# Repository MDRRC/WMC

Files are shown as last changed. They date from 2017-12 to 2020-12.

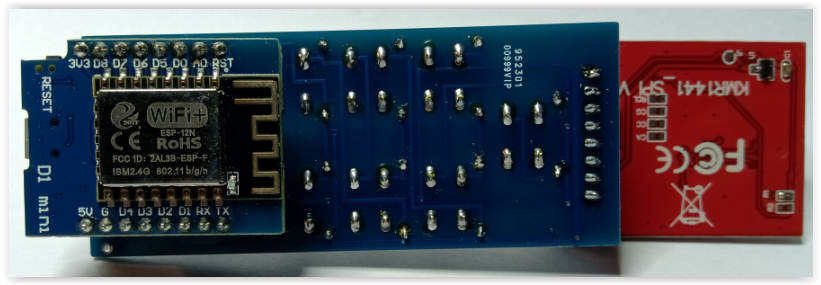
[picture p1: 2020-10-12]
Images/wmc_back.PNG

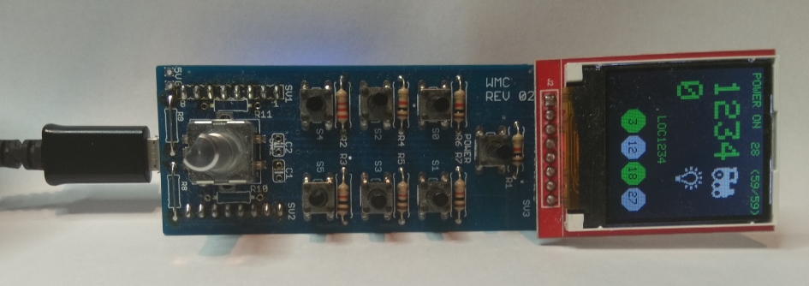
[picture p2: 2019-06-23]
Images/wmc_locname.jpg

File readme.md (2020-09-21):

Wifi Manual Control
=====================

The Wifi Manual Control (Wmc) is a project which supports the [Z21 protocol](https://www.z21.eu/en) of [Roco](https://www.roco.cc/en/home/index.html) to control locomotives and turnouts. Also CV's can be read and written. 
The design is based on an ESP8266-12E processor (Wemos Mini D1 for example), an ST7735 1.44 inch display, rotary (pulse) switch and some push buttons. 
For more info see the [wiki](https://github.com/MDRRC/WMC/wiki).

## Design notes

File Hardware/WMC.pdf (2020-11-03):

WMC

# WMC

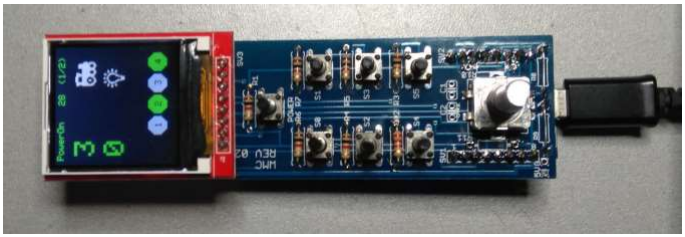
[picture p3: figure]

Version 4 | 3/11/2020 | 1 van 8

## Inhoudsopgave

Version 4 | 3/11/2020 | 2 van 8

1. Introduction.

This document describes how to mount components on the WMC PCB (REV 02) and how to pogram the ESP8266 module withput the need for installing Arduino¹
on a
system and building all code.

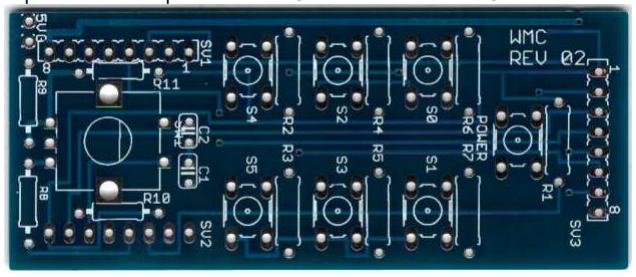
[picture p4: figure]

A description of how to operate the WMC can be found on the Github wiki²

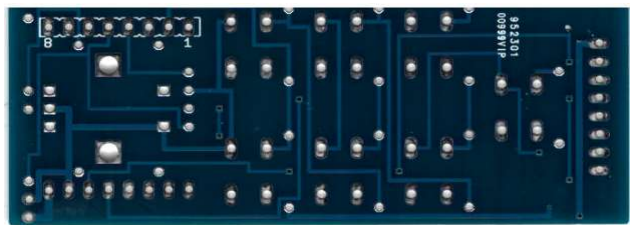
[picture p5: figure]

### 1.1 Used components

- Wemos ESP8266 D1 mini³
- S7735 display. Buy the so called “Replace Nokia 5110/3310 LCD”. Other displays will work but might not be directly soldered on connector SV3 as they might be not pin compatible.
- Some resistors, see schematic for values.
- 7 push buttons DIP P4
- Pulse switch (rotary pulse swith)

### 1 https://www.arduino.cc/ 2 https://github.com/MDRRC/WMC/wiki 3 https://wiki.wemos.cc/products:d1:d1_mini

Version 4 | 3/11/2020 | 3 van 8

2. Soldering components.
1. Solder the push buttons and the resistors.

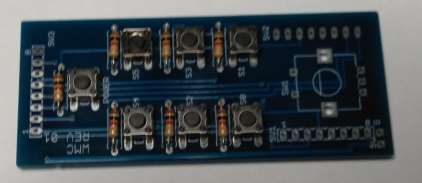
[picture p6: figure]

### 2. Solder the pulse switch and cut the solder points very short (solder points

marked with yellow arrow) so they can not make contact with the Wemos ESP8266 module.

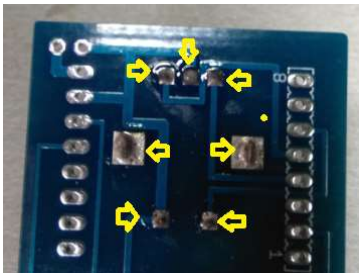
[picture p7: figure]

Version 4 | 3/11/2020 | 4 van 8

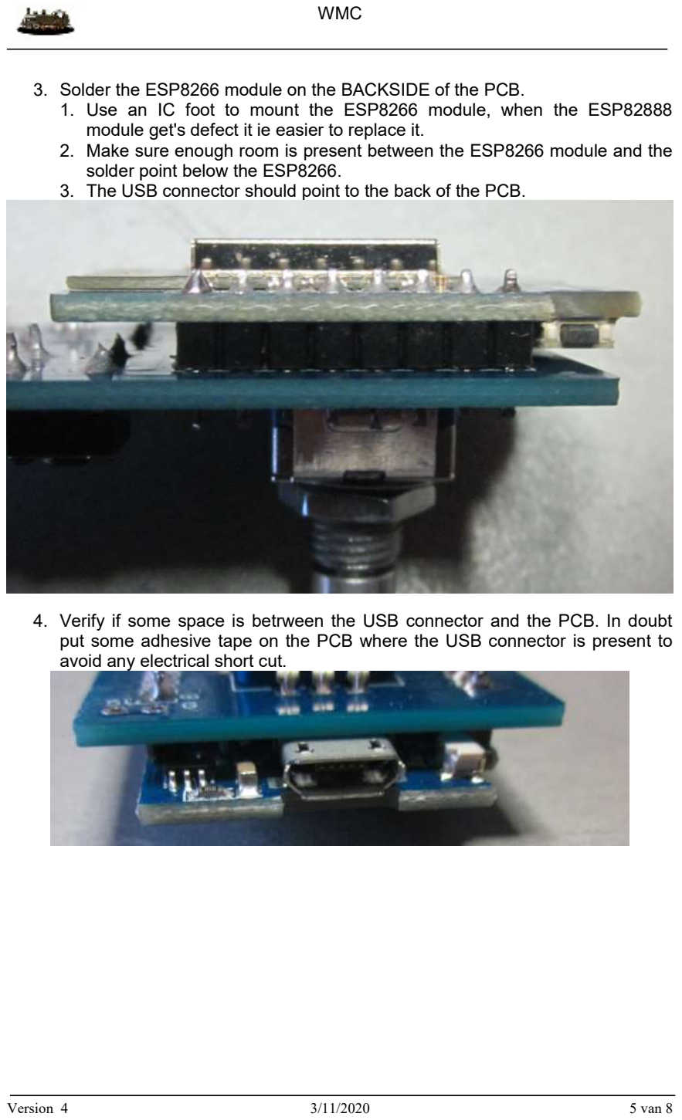
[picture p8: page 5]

3. Solder the ESP8266 module on the BACKSIDE of the PCB.

### 1. Use an IC foot to mount the ESP8266 module, when the ESP82888

module get's defect it ie easier to replace it.

### 2. Make sure enough room is present between the ESP8266 module and the

solder point below the ESP8266.
3. The USB connector should point to the back of the PCB.

### 4. Verify if some space is betrween the USB connector and the PCB. In doubt

put some adhesive tape on the PCB where the USB connector is present to avoid any electrical short cut.

Version 4 | 3/11/2020 | 5 van 8

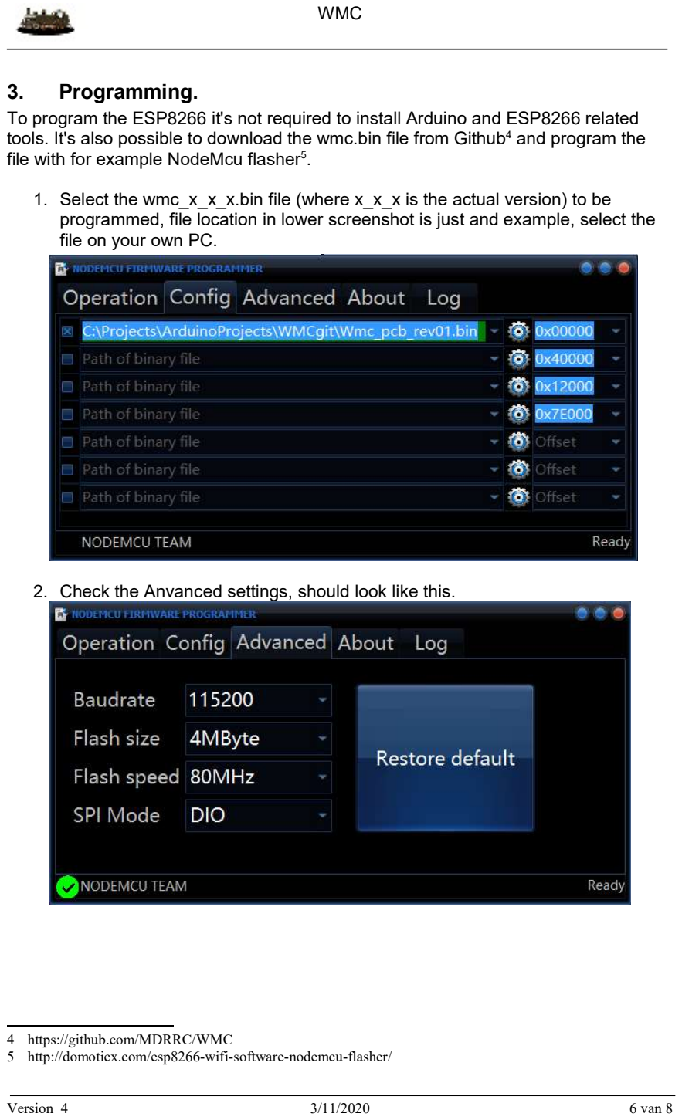
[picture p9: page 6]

3. Programming.
To program the ESP8266 it's not required to install Arduino and ESP8266 related tools. It's also possible to download the wmc.bin file from Github⁴
and program the
file with for example NodeMcu flasher⁵

### 1. Select the wmc_x_x_x.bin file (where x_x_x is the actual version) to be

programmed, file location in lower screenshot is just and example, select the file on your own PC.

2. Check the Anvanced settings, should look like this.

### 4 https://github.com/MDRRC/WMC 5 http://domoticx.com/esp8266-wifi-software-nodemcu-flasher/

Version 4 | 3/11/2020 | 6 van 8

### 3. Select the com port of the ESP8266 module and press Flash. Takes some

time to program...

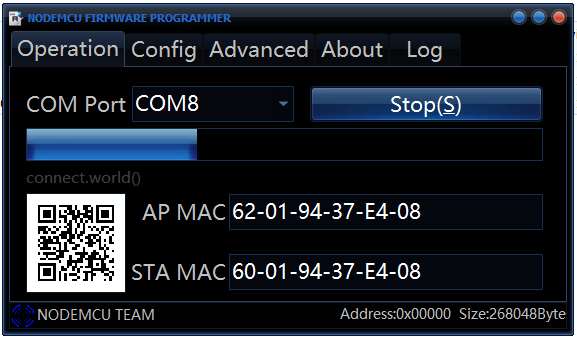
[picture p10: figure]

Version 4 | 3/11/2020 | 7 van 8

4. Changes.
Version | Date | Desciption
1 | 05-05-18 | Initial version
2 | 17-05-18 | 1 Introduction. Added link to how to operate the WMC. 3 Programming. Filename and screenshot updated.
3 | 17-11-18 | Some PCB images updated. 3 Programming. Filename updated.
4 | 03-11-20 | 1.1 Used components Test of resistors updated.
Version 4 | 3/11/2020 | 8 van 8

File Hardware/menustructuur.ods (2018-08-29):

Hoe te gebruiken | betreft | PushButton PB | D0 1 / 0 Power button | S0 | S1 | S2 | S3 | S4 | S5 | Puls schakelaar
rijden |  |  | aan uit 1 / 0
 |  | <200ms loc stop OF richting als snelheid al 0 is |  | licht / functie | functie | functie | functie | functie | wisselmodus | snelheid
 |  | 1 sec richting
 |  | >3 sec POM
wisselmodus |  |  |  |  |  |  |  |  | activeren
 |  | <200ms = 1 |  | adres +1 | Adres +10 | Adres +100 | Adres +1000 | wissel L | wissel R | adres
 |  | 1 sec = locbesturing
MENU_1 |  |  | PowerOff |  |  |  |  |  |  | Menu 2
 |  | >4 sec
ADD (S1) |  |  |  |  | ADD loc toevoegen
loc toevoegen | loc | OK |  | Loc + 1 | Loc + 10 | Loc + 100 | Loc + 1000 | Adres = 1 | OK | loc selecteren
functies toekennen | functie | OK |  | licht F0 OF ken andere fucntie toe | ken functie toe aan knop (maar geen F0) | ken functie toe aan knop (maar geen F0) | ken functie toe aan knop (maar geen F0) | ken functie toe aan knop (maar geen F0) | OK | kies functie nr.
 |  |  | afsluiten
CHANGE (S2) |  |  | PowerOff |  |  | CHANGE functie wijzigen
functie wijzigen | Selecteer loc | gedrukt houden |  |  |  |  |  |  |  | loc selecteren
 | functie | OK |  | licht F0 OF ken andere fucntie toe | ken functie toe aan knop (maar geen F0) | ken functie toe aan knop (maar geen F0) | ken functie toe aan knop (maar geen F0) | ken functie toe aan knop (maar geen F0) | OK | kies gewenste functie
 |  |  | ga terug naar het MENU
DELETE (S3) |  |  | PowerOff |  |  |  | DELETE verwijder loc
Verwijder een loc | Selecteer loc | OK |  |  |  |  |  |  |  | selecteer loc
 |  | >1 sec verwijder loc |  | ga terug naar het MENU | ga terug naar het MENU | ga terug naar het MENU | ga terug naar het MENU | ga terug naar het MENU | ga terug naar het MENU
 |  |  | ga terug naar het MENU
MENU_2 |  |  | PowerOff |  |  |  |  |  |  | Menu 1
 |  | >4 sec
DELL LOCS (S1) | Verwijder ALLE locomotieven
DELL ALL (S2) | Verwijder ALLE data
CV PROG (S4) |  |  | PowerOff |  |  |  |  | CV PROG cv programmeren op programmeer rail
 | loc op programmeerrail
 |  | <200msec = terug naar MENU > 1sec Naar Cv nummer Naar CV waarde Schrijf waarde |  | waarde +1 | Waarde +10 | Waarde +100 | Waarde +1000 | Cv nummer = 1 CV waarde = 1 | Lees waarde Schrijf waarde | selecteer waarde CV nummer
 |  |  | ga terug naar het MENU
POM PROG (S5) |  |  | schakel AAN 1 / 0 PowerOn |  |  |  |  |  | POM PROG CV programmeren POM
 | loc |  |  |  |  |  |  |  |  | loc selecteren
 |  | <200msec = terug naar menu > 1sec Naar Cv nummer Naar CV waarde Schrijf waarde |  | waarde +1 | Waarde +10 | Waarde +100 | Waarde +1000 | Pom adres = 1 Cv nummer = 1 Cv waarde = 1 | Naar Cv nummer Naar CV waarde Schrijf waarde | selecteer waarde CV nummer
 |  |  | ga terug naar het MENU

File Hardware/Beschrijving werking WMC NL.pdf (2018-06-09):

30-5-2018

## WMC

Dit is een vertaling van de originele beschrijving van Robert Evers. Deze vertaling is gemaakt voor eigengebruik. Eventuele fouten hierin komen dus volledig door mijn¹
vertaalkunsten en gebruiken is dan ook geheel voor eigen risico. Ieder die een actuele beschrijving wenst te hebben moet deze bij Robert Evers betrekken bijvoorbeeld via https://github.com/MDRRC/WMC/wiki
Met enkele goedkope componenten kan een eenvoudige op Wifi gebaseerde handmatige bediening worden gemaakt voor het Z21 protocol. (http://www.z21.eu/en) Het is volgende is mogelijk:
- Rijsnelheid, richting en functies van locomotieven.
- Wissels instellen (accessoire-decoders).
- Programmeren CV's van locdecoders (Programmeerrail en POM)

De NodeMcu kan worden geprogrammeerd met de Arduino-omgeving, u moet ondersteuning voor de ESP8266 installeren in de Arduino-omgeving. (gebruik op eigen risico !!!!). Het display is een 128 * 128 pixel ST7735 LCD-scherm.
De WMC is (nog) niet getest met een Roco (http://www.roco.cc/en/home/index.html) (z) / Z21 Wifi-commandostation, alleen met
- MDRRC-II (http://members.home.nl/robert.evers/mdrrc2.htm)
- DigiKeys DR 5000 (CV / POM (https://www.digikeijs.nl/dr5000adj-dcc-multi-bus-centrale.html) niet getest (https://www.digikeijs.nl/dr5000adj-dcc-multi-bus-centrale.html) ) (https://www.digikeijs.nl/dr5000adj-dcc-multi-bus-centrale.html)
- DIY Z21 Emulator (CV / POM (https://www.gscalecentral.net/threads/diy-emulator-of-z21-command-station-based-on-arduino-for-20.305794/) niet getest (https://www.gscalecentral.net/threads/diy-emulator-of-z21-command-station-based-on-arduino-for-20.305794/) ). (https://www.gscalecentral.net/threads/diy-emulator-of-z21-command-station-based-on-arduino-for-20.305794/)

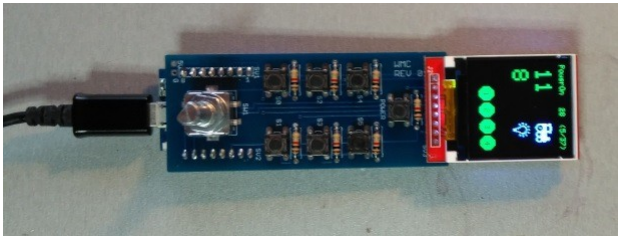
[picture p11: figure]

Hoe te gebruiken.

Programmeer eerst de SSID (Wifi) -naam, het wifi-wachtwoord en het Z21-control-IP-adres met behulp van de commandoregel-interface, zie verder onder.

1 http://members.home.nl/pamali/

De drukknop op D0 is de Aan / Uitknop.

- Als de stroom is ingeschakeld, draait u de pulsschakelaar links / rechts om de snelheid van de geselecteerde locomotief te regelen.
- Kort indrukken (~ 200msec) en het loslaten van de pulsschakelaar is de locomotief-stop.
- Normale druk (~ 1sec) en het loslaten van de pulsschakelaar is de richting van de locomotief omdraaien.
- Lang indrukken (> 3 sec.) En loslaten van pulsschakelaar is POM-programmeermodus voor locomotieven.
- Druk op een van de functieknoppen om de geprogrammeerde functie om te schakelen wanneer de knop wordt losgelaten.
- Door op S5 te drukken en los te laten, wordt de wisselmodus ingevoerd.
- Om een andere loc te selecteren, drukt en draait u de pulsschakelaar om een geprogrammeerde loc te selecteren.
- Als een geselecteerde loc al in gebruik is door een ander apparaat, wordt het loc-symbool op het scherm geel.

Wissel modus

- Druk op de knoppen SO ... S3 om het adres te verhogen door de pulsschakelaar te draaien.
- Druk op S4 of S5 om de richting van de wissel te veranderen.
- Druk kort op de pulsdrukknop om het wisseladres opnieuw in te stellen op 1.
- Normale druk op pulsschakelaar is terug naar locomotiefbesturing.

MENU

- Zorg ervoor dat PowerOff is weergegeven.
- Druk gedurende ten minste 4 seconden op de drukknop van de pulsschakelaar.
- Een menu verschijnt.

Locomotieven toevoegen (ADD)

- Druk op knop S1 om locomotieven toe te voegen
- Draai de pulsschakelaar om het loc-adres te selecteren. Met de knoppen S1 – S4 kunnen adressen worden verhoogd met 1,10,100 en 1000. Met knop 0 kan het adres worden gereset naar 1.
- Als het gewenste adres in orde is, drukt u op de pulsschakelaarknop.
- Als het adres een rode kleur wordt, is het adres al aanwezig in WMC.
- Ken nu functies toe aan de knoppen. Draai de pulsschakelaar, en kies een functie, wanneer de functie bereikt is, druk op de bijbehorende functieknop. Knop 0 kan alleen licht schakelen.
- Om de toegevoegde loc op te slaan, drukt u op de drukknop van de pulsschakelaar.
- Om het toevoegen van locomotieven af te sluiten, drukt u op de aan / uitknop D0.

Functies wijzigen (CHANGE)

- Kies in het menu knop S2 CHANGE – Wijzigen.
- Druk en draai de pulsschakelaar om de locomotief te selecteren.
- Draai de pulsschakelaar naar de gewenste functie.
- Druk op de toepasselijke functieknop.
- Druk op de schakelaar van de pulsschakelaar om de gegevens op te slaan.
- Het loc-adres zal geel worden, om te bevestigen dat de wijziging is opgeslagen.
- Om Wijzigen van de loc-functies te verlaten, drukt u op de Aan / Uit - knop D0.

Verwijder een loc. (DELETE)

- Selecteer in het menu knop S3 DELETE – Verwijderen.
- Draai aan de pulsschakelaar om de locomotief te selecteren die moet worden verwijderd.
- Druk op de pulsschakelaarknop om de loc te verwijderen.
- Druk op de aan / uitknop D0 om het verwijderen van locs af te sluiten.

Programmeren CV's op programmeerrail (CV PROG)

- Selecteer in het menu knop S4 CV Prog.
- Draai de pulsschakelaar om het CV-nummer te wijzigen en / of druk op de knoppen 1 .. 3 om de waarde te verhogen.
- Druk op knop S0 om het CV-nummer te resetten.
- Druk na het invoeren van het CV-nummer op> 1sec op de pulsschakelaar-drukknop (en laat los), de waarde zal worden gelezen.
- Nadat de CV-waarde is afgelezen, draait u de pulsschakelaar om het CV-nummer te wijzigen en / of drukt u op de knoppen 1 .. 3 om de waarde te verhogen.
- Druk op knop S0 om de CV-waarde te resetten.
- Druk na het invoeren van de CV-waarde op> 1 sec. Op de pulsdrukknop (en laat los), de waarde wordt geschreven.
- Druk nogmaals > 1sec op de pulsschakelaar- drukknop, om de waarde te lezen.
- Druk Aan / Uit - knop D0 om terug te keren naar het MENU (een stap terug)
- Druk Aan / Uit - knop D0 om terug te keren naar het LOC – MENU (een stap terug)
- Als u tijdens het invoeren van het CV-nummer of de CV-waarde op de Aan / Uit -knop D0 drukt, keert u terug naar het hoofdmenu.

Programmeren CV's met POM (POM PROG)

- Druk Aan / Uit - knop D0
- Power is ON
- Selecteer in het menu knop S5 POM PROG
- Procedure is hetzelfde als hierboven, maar eerst moet de gewenste locomotief worden ingevoerd.
- De cv-waarde wordt NIET gelezen.

Commandoregel-interface met Putty of Realterm.

Met Putty (http://www.putty.org/) of Realterm (https://sourceforge.net/projects/realterm/) opent u bijvoorbeeld de seriële poort van de NodeMcu, baudrate 115200.
Met de (eenvoudige) opdrachtregelinterface kunt u dit doen:
help | Het complete menu met alle opdrachtregels
add | Voeg een loc toe.
del | Verwijder een loc.
change x y z | Toegewezen functies wijzigen in knoppen van een locomotief. (adres=x, ftoets=y, functie=z)
ssid < > | Stel SSID (Wifi) naam in. (<wifi naam>)
Password < > | Stel wifi-wachtwoord in. (<paswoord>)
z21 a.b.c.d | Stel het IP-adres in waarmee het Z21-besturingselement verbinding maakt.
static x | Schakel tussen statisch en dynamisch IP-adres van de WMC (x=0). In de statische modus (x=1) moet u het IP-adres van de WMC invoeren.

Aansluitingen

NodeMcu | onderdeel
D0 | Drukknop naar massa en 1K weerstand naar 3V3 voedingsspanning voor
| pullup (geen draai/drukknop met voorgemonteerde weerstanden gebruiken!)
D1 | DC ST7735-display
D2 | RES ST7735-display
D3 | SCL ST7735-display
D4 | SDA ST7735-display
D5 | CLK draaischakelaar
D6 | DATA draaischakelaar
D7 | Drukknop draaischakelaar (geen draai/drukknop met voorgemonteerde
| weerstanden gebruiken!)
D8 | CS ST7735-display
A0 | Analoge ingang voor functieschakelaars, zie hieronder.

Schema zie h (https://github.com/MDRRC/WMC/blob/master/Hardware/wmc_schematic.pdf) ier (https://github.com/MDRRC/WMC/blob/master/Hardware/wmc_schematic.pdf). (https://github.com/MDRRC/WMC/blob/master/Hardware/wmc_schematic.pdf)

Gebruikte bibliotheken

- WmcStm (https://github.com/MDRRC/WmcStm) the state machine of the application.
- TinyFsm (https://github.com/digint/tinyfsm) for state machine framework.
- Z21 Slave (https://github.com/MDRRC/Z21Slave) for Z21 protocol.
- Bounce2 (https://github.com/thomasfredericks/Bounce2) for debouncing a switch.
- Adafruit-ST7735-Library (https://github.com/adafruit/Adafruit-ST7735-Library) to control the display.
- WmcTft (https://github.com/MDRRC/WmcTft) for graphics within the Wmc application.
- Adafruit-GFX-Library (https://github.com/adafruit/Adafruit-GFX-Library) for graphic control of the display.

- LocLib (https://github.com/MDRRC/LocLib) for handling locomotive data within the Wmc application. WmcCv (https://github.com/MDRRC/WmcCv) for changing CV's.

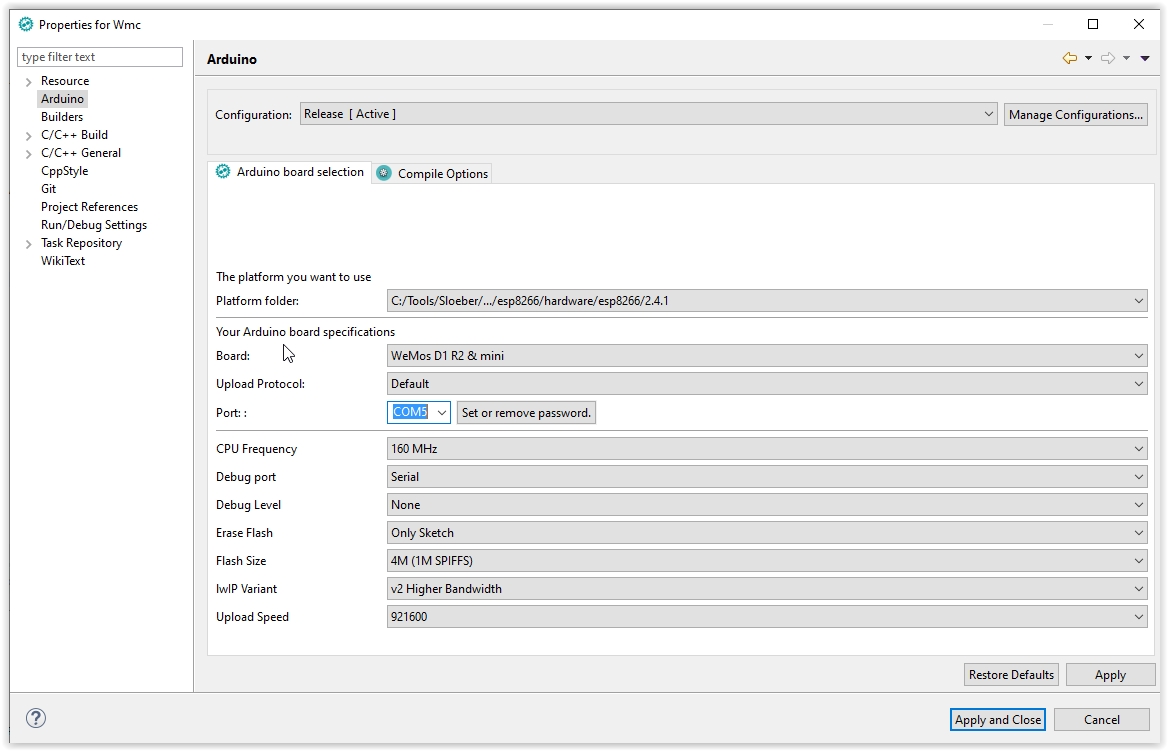
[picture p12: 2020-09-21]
Images/sloeber_settings.JPG

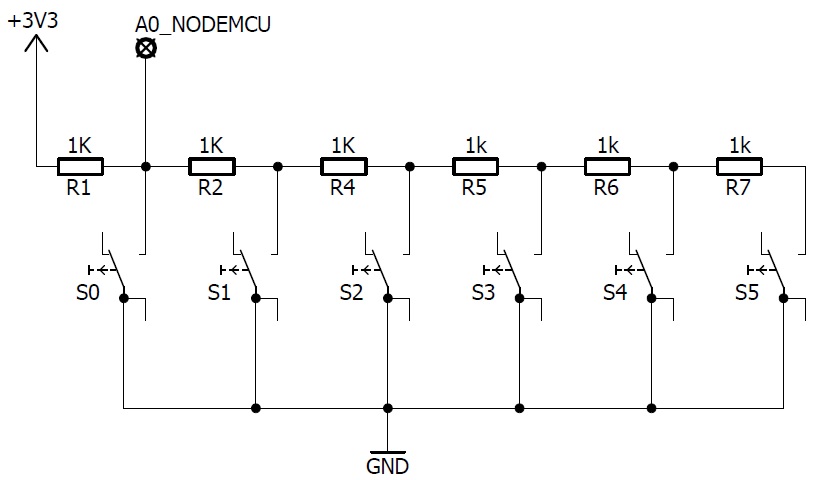
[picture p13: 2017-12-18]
Images/analog_switches.jpg

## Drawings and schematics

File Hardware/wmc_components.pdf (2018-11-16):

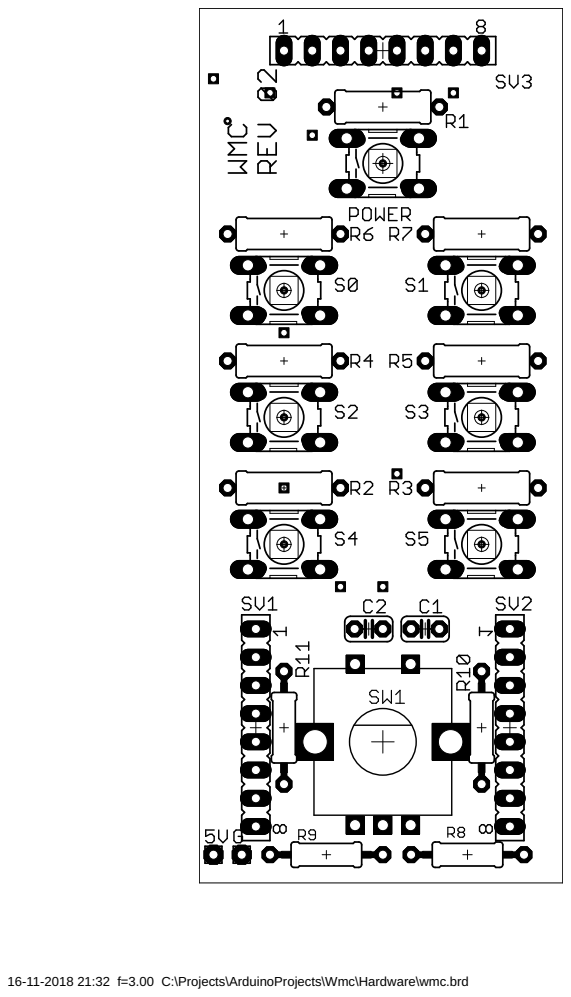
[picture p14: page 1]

16-11-2018 21:32 f=3.00 C:\Projects\ArduinoProjects\Wmc\Hardware\wmc.brd

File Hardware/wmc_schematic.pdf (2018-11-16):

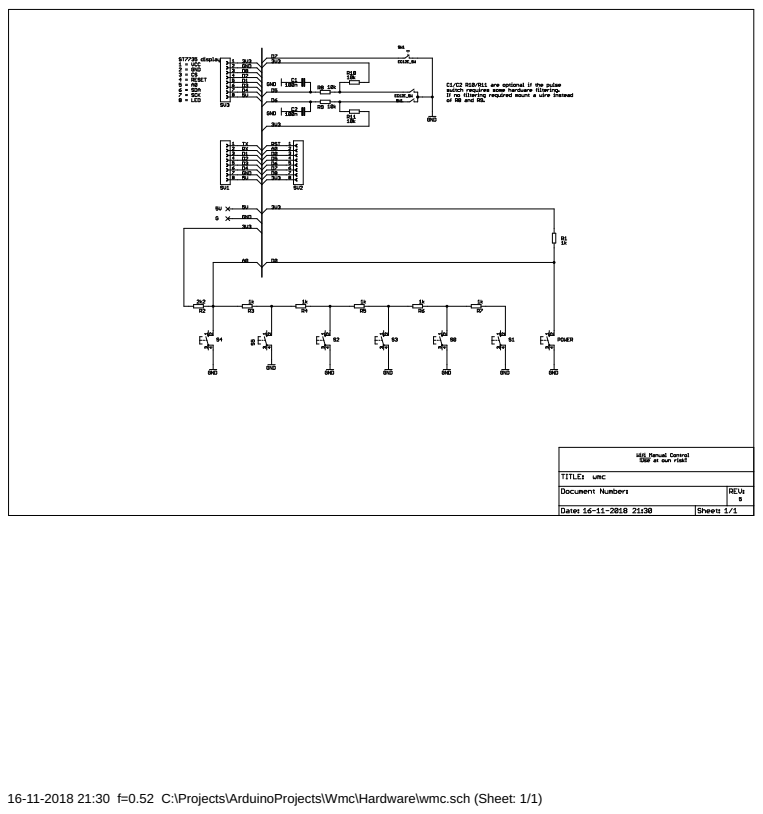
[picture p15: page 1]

16-11-2018 21:30 f=0.52 C:\Projects\ArduinoProjects\Wmc\Hardware\wmc.sch (Sheet: 1/1)

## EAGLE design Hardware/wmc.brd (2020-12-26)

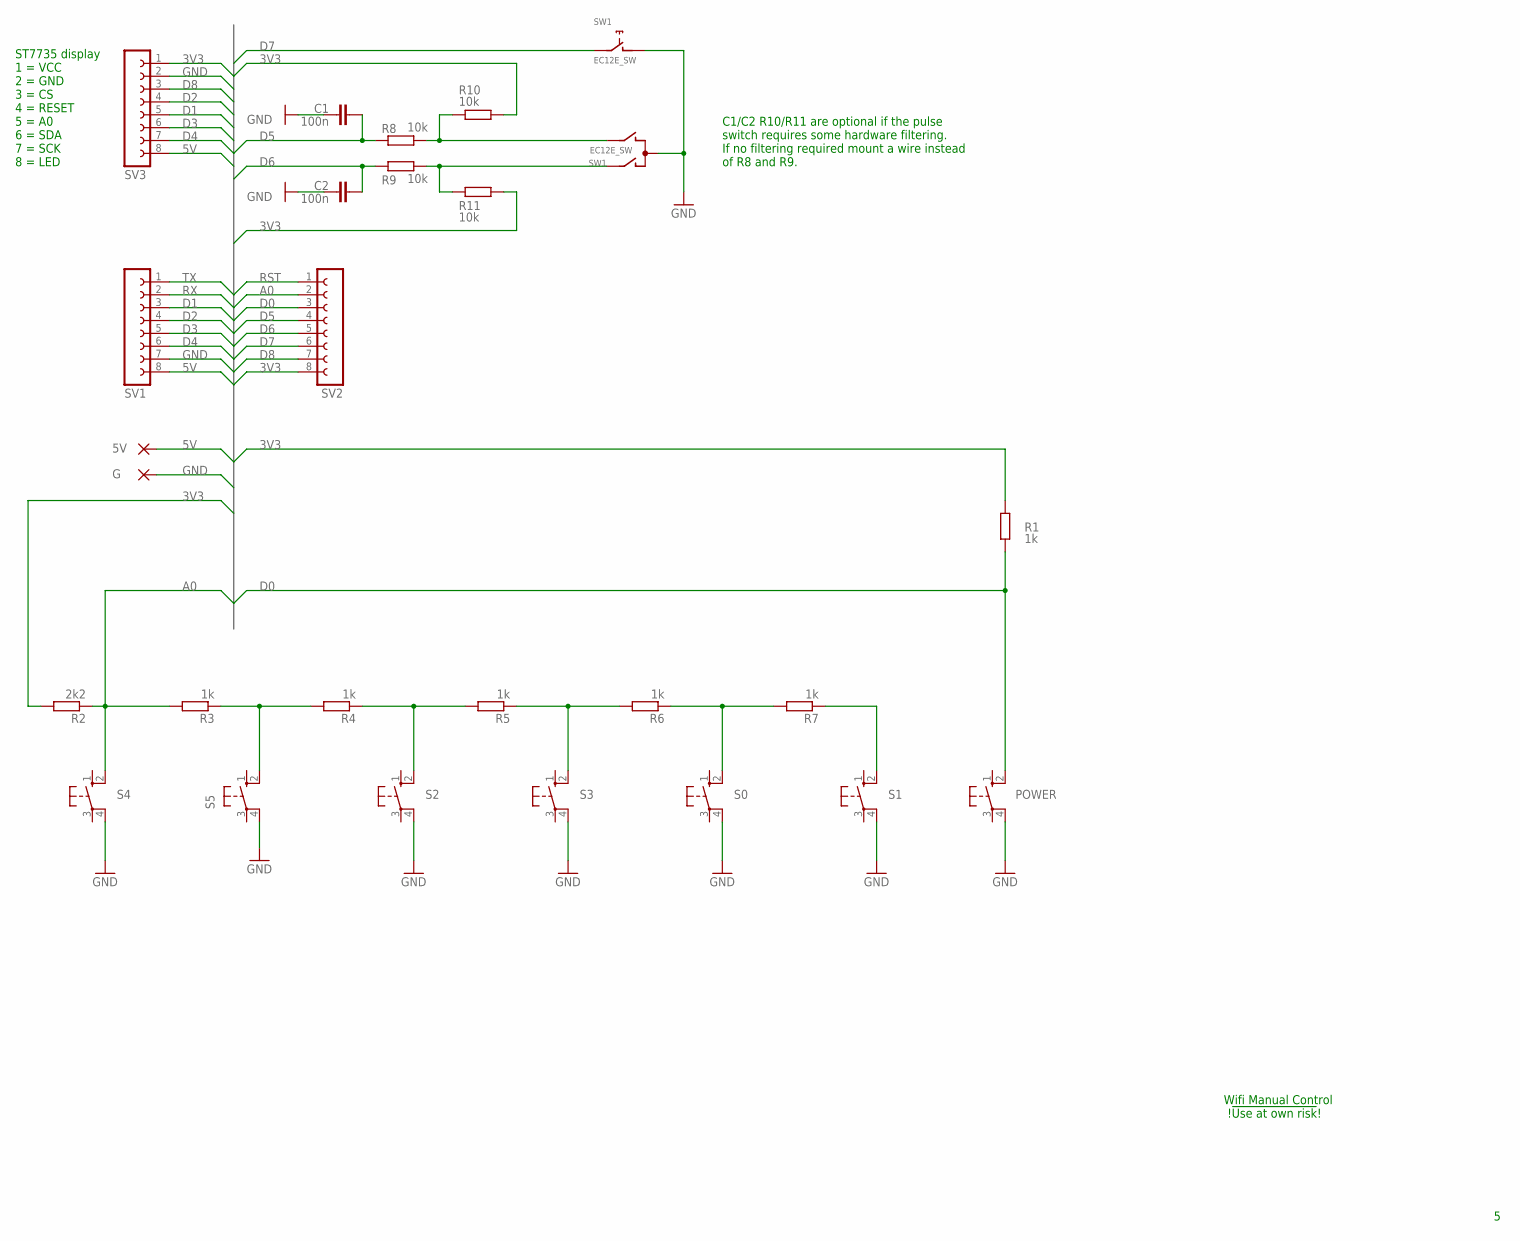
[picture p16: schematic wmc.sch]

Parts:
5V: 1,6/0,8
C1, C2: 100n; C025-024X044
G: 1,6/0,8
POWER: 10-XX; B3F-10XX
R1, R3, R4, R5, R6, R7: 1k; 0309/10
R2: 2k2; 0309/10
R8, R9, R10, R11: 10k; 0207/10
S0, S1, S2, S3, S4, S5: 10-XX; B3F-10XX
SV1, SV2, SV3: FE08-1; FE08
SW1: EC12E_SW; ALPS_EC12E_SW

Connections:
3V3: R1.2, R2.2, R10.2, R11.2, SV2.8, SV3.1
5V: 5V.1, SV1.8, SV3.8
A0: R2.1, R3.2, S4.2 (S1), SV2.2
D0: POWER.2 (S1), R1.1, SV2.3
D1: SV1.3, SV3.5
D2: SV1.4, SV3.4
D3: SV1.5, SV3.6
D4: SV1.6, SV3.7
D5: C1.1, R8.1, SV2.4
D6: C2.1, R9.1, SV2.5
D7: SV2.6, SW1.E (2)
D8: SV2.7, SV3.3
GND: C1.2, C2.2, G.1, POWER.4 (P1), S0.4 (P1), S1.4 (P1), S2.4 (P1), S3.4 (P1), S4.4 (P1), S5.4 (P1), SV1.7, SV3.2, SW1.C, SW1.D (1)
unnamed: R7.1, S1.2 (S1)
unnamed: R3.1, R4.2, S5.2 (S1)
unnamed: R4.1, R5.2, S2.2 (S1)
unnamed: R5.1, R6.2, S3.2 (S1)
unnamed: R6.1, R7.2, S0.2 (S1)
unnamed: R8.2, R10.1, SW1.B
unnamed: R9.2, R11.1, SW1.A
RST: SV2.1
RX: SV1.2
TX: SV1.1

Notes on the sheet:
Wifi Manual Control !!Use at own risk!!
ST7735 display 1 = VCC 2 = GND 3 = CS 4 = RESET 5 = A0 6 = SDA 7 = SCK 8 = LED
C1/C2 R10/R11 are optional if the pulse switch requires some hardware filtering. If no filtering required mount a wire instead of R8 and R9.

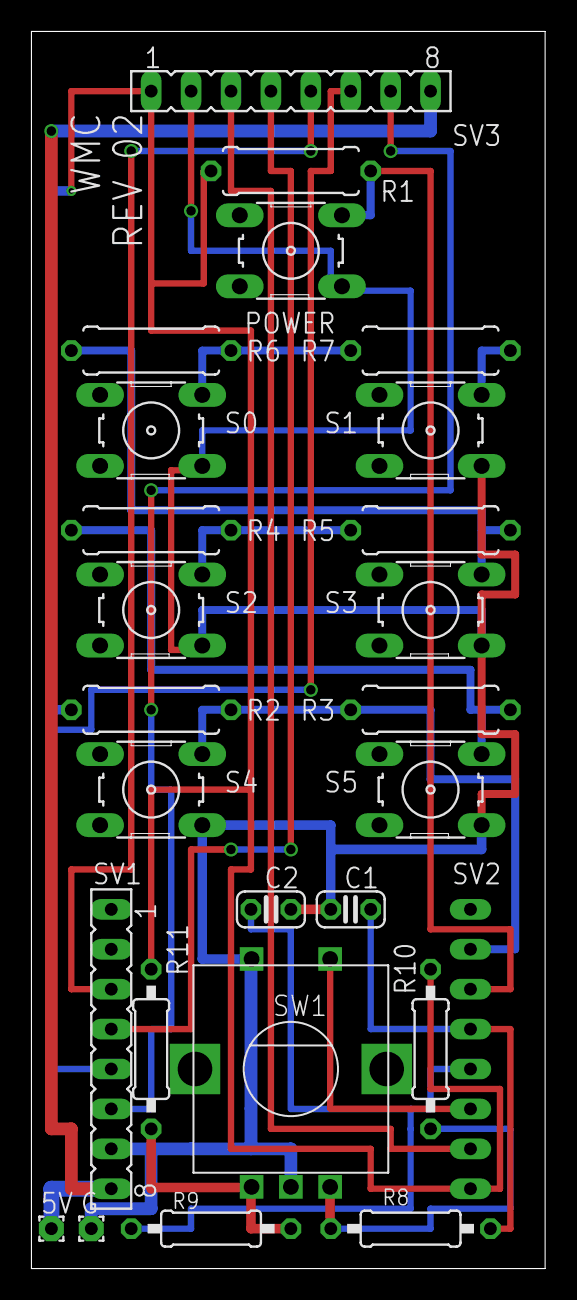
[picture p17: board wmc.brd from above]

Board: 2 copper layers, 32.7 x 78.7 mm, 26 parts (1 on the bottom side), 20 nets.

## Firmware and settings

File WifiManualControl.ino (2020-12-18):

/***********************************************************************************************************************
   @file
   @ingroup
   @brief
 **********************************************************************************************************************/

/***********************************************************************************************************************
   I N C L U D E S
 **********************************************************************************************************************/
#include "Bounce2.h"
#include "Loclib.h"
#include "WmcTft.h"
#include "Z21Slave.h"
#include "app_cfg.h"
#include "fsmlist.hpp"
#include "wmc_event.h"

/***********************************************************************************************************************
   E X P O R T E D   S Y M B O L   D E F I N I T I O N S (defines, typedefs)
 **********************************************************************************************************************/
#define WMC_PULSE_SWITCH_UPDATE_TIME 50
#define encoder0PinA D5
#define encoder0PinB D6

/***********************************************************************************************************************
   D A T A   D E C L A R A T I O N S (exported, local)
 **********************************************************************************************************************/

Bounce WmcPowerOffOnButton      = Bounce();
Bounce WmcPulseSwitchPushButton = Bounce();

unsigned long WmcStartMsPulseSwitchPushButton;
unsigned long WmcUpdateTimer3Seconds;
unsigned long WmcUpdatePulseSwitch;
unsigned long WmcUpdateTimer5msec;
unsigned long WmcUpdateTimer50msec;
unsigned long WmcUpdateTimer100msec;
unsigned long WmcUpdateTimer500msec;

// buffer to hold incoming and outgoing packets
bool turnedWhilePressed      = false;
int16_t encoder0PosActual    = 0;
volatile int16_t encoder0Pos = 0;

uint8_t WmcButton;

updateEvent3sec wmcUpdateEvent3Sec;
pushButtonsEvent wmcPushButtonEvent;
pulseSwitchEvent wmcPulseSwitchEvent;
updateEvent5msec wmcUpdateEvent5msec;
updateEvent50msec wmcUpdateEvent50msec;
updateEvent100msec wmcUpdateEvent100msec;
updateEvent500msec wmcUpdateEvent500msec;

/***********************************************************************************************************************
   L O C A L   F U N C T I O N S
 **********************************************************************************************************************/

/***********************************************************************************************************************
 */
static bool WmcUpdate5msec(void)
{
    bool Result = false;

    if (millis() - WmcUpdateTimer5msec > 5)
    {
        Result              = true;
        WmcUpdateTimer5msec = millis();
        send_event(wmcUpdateEvent5msec);
    }

    return (Result);
}

/***********************************************************************************************************************
 */
static bool WmcUpdate50msec(void)
{
    bool Result = false;

    if (millis() - WmcUpdateTimer50msec > 50)
    {
        Result               = true;
        WmcUpdateTimer50msec = millis();
        send_event(wmcUpdateEvent50msec);
    }

    return (Result);
}

/***********************************************************************************************************************
 */
static bool WmcUpdate100msec(void)
{
    bool Result = false;

    if (millis() - WmcUpdateTimer100msec >= 100)
    {
        Result                = true;
        WmcUpdateTimer100msec = millis();
        send_event(wmcUpdateEvent100msec);
    }

    return (Result);
}

/***********************************************************************************************************************
 */
static bool WmcUpdate500msec(void)
{
    bool Result = false;

    if (millis() - WmcUpdateTimer500msec >= 500)
    {
        Result                = true;
        WmcUpdateTimer500msec = millis();
        send_event(wmcUpdateEvent500msec);
    }

    return (Result);
}

/***********************************************************************************************************************
 */
static bool WmcUpdate3Sec(void)
{
    bool Result = false;
    if (millis() - WmcUpdateTimer3Seconds > 3000)
    {
        Result                 = true;
        WmcUpdateTimer3Seconds = millis();
        send_event(wmcUpdateEvent3Sec);
    }

    return (Result);
}

/***********************************************************************************************************************
 */
void ICACHE_RAM_ATTR doEncoderA()
{
    // look for a low-to-high on channel A
    if (digitalRead(encoder0PinA) == HIGH)
    {
        // check channel B to see which way encoder is turning
        if (digitalRead(encoder0PinB) == LOW)
        {
            // CW
            encoder0Pos++;
        }
        else
        {
            // CCW
            encoder0Pos--;
        }
    }
    else // must be a high-to-low edge on channel A
    {
        // check channel B to see which way encoder is turning
        if (digitalRead(encoder0PinB) == HIGH)
        {
            // CW
            encoder0Pos++;
        }
        else
        {
            // CCW
            encoder0Pos--;
        }
    }
}

/***********************************************************************************************************************
 */
int8_t DecoderUpdate(void)
{
    int8_t Delta = 0;
    if (encoder0Pos != encoder0PosActual)
    {
        Delta             = (int8_t)(encoder0Pos - encoder0PosActual);
        encoder0PosActual = encoder0Pos;
    }

    return (Delta);
}

/***********************************************************************************************************************
   E X P O R T E D   F U N C T I O N S
 **********************************************************************************************************************/

/**
 ******************************************************************************
   @brief
   @param
   @return     None
 ******************************************************************************/
void setup()
{
    Serial.begin(115200);

    /* Init the pulse / rotary encoder. */
    pinMode(encoder0PinA, INPUT_PULLUP);
    pinMode(encoder0PinB, INPUT_PULLUP);
    attachInterrupt(digitalPinToInterrupt(encoder0PinA), doEncoderA, CHANGE);

    /* Init debounces for switches. */
    pinMode(D7, INPUT_PULLUP);
    WmcPulseSwitchPushButton.interval(100);
    WmcPulseSwitchPushButton.attach(D7);

    pinMode(D0, INPUT_PULLUP);
    WmcPowerOffOnButton.interval(100);
    WmcPowerOffOnButton.attach(D0);

    /* Init timers. */
    WmcUpdateTimer3Seconds          = millis();
    WmcUpdatePulseSwitch            = millis();
    WmcUpdateTimer50msec            = millis();
    WmcUpdateTimer100msec           = millis();
    WmcUpdateTimer500msec           = millis();
    WmcUpdateTimer3Seconds          = millis();
    WmcStartMsPulseSwitchPushButton = millis();

    /* Kick the state machine. */
    fsm_list::start();
}

/**
 ******************************************************************************
   @brief
   @param
   @return     None
 ******************************************************************************/
void loop()
{
    int8_t Delta = 0;

    /* Check for timed events. */
    WmcUpdate5msec();
    WmcUpdate50msec();
    WmcUpdate100msec();
    WmcUpdate500msec();
    WmcUpdate3Sec();

    /* Update button status. */
    WmcPowerOffOnButton.update();
    WmcPulseSwitchPushButton.update();

    /* Check for button changes and generate evbent if required. */
    if (WmcPowerOffOnButton.rose() == true)
    {
        wmcPushButtonEvent.Button = button_power;
        send_event(wmcPushButtonEvent);
    }

    /* Pulse switch push button handling. When releasing button check time and generate event based on time.*/
    if (WmcPulseSwitchPushButton.fell() == true)
    {
        WmcStartMsPulseSwitchPushButton = millis();
    }
    else if (WmcPulseSwitchPushButton.rose() == true)
    {
        if (turnedWhilePressed == false)
        {
            if (millis() - WmcStartMsPulseSwitchPushButton > 3000)
            {
                wmcPulseSwitchEvent.Status = pushedlong;
                send_event(wmcPulseSwitchEvent);
            }
            else if (millis() - WmcStartMsPulseSwitchPushButton < 300)
            {
                wmcPulseSwitchEvent.Status = pushedShort;
                send_event(wmcPulseSwitchEvent);
            }
            else if (millis() - WmcStartMsPulseSwitchPushButton < 1100)
            {
                wmcPulseSwitchEvent.Status = pushedNormal;
                send_event(wmcPulseSwitchEvent);
            }
        }
        else
        {
            turnedWhilePressed         = false;
            wmcPulseSwitchEvent.Status = released;
            send_event(wmcPulseSwitchEvent);
        }
    }
    else if ((millis() - WmcUpdatePulseSwitch) > WMC_PULSE_SWITCH_UPDATE_TIME)
    {
        /* Update pulse switch turn events if turned.*/
        WmcUpdatePulseSwitch = millis();
        Delta                = DecoderUpdate();
        if (Delta != 0)
        {
            if (WmcPulseSwitchPushButton.read() == LOW)
            {
                turnedWhilePressed         = true;
                wmcPulseSwitchEvent.Status = pushturn;
            }
            else
            {
                wmcPulseSwitchEvent.Status = turn;
            }

            wmcPulseSwitchEvent.Delta = Delta;

            send_event(wmcPulseSwitchEvent);
        }
    }
}

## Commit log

2017-10-16 Extra check states and received data to avoid overwriting status row each time.
    [WifiManualControl.ino]
2017-10-16 Schematic corrected.
2017-12-18 Uodated image with extra switch and updated resistors.
2017-12-18 Analog values for switches updated after adding 5th switch.
2018-02-04 Timer test of WmcUpdatePulseSwitch wrong, corrected it.
    [WifiManualControl.ino]
2018-03-21 Rotary (pulse) switch inputs use internal pull ups of the ESP8266.
2018-05-01 Added schematic.
2018-05-05 Added document for mounting components onm PCB and programming the ESP8266 module without the need for a full developer version on a PC.
2018-05-05 Added bin file for PCB version 01.
2018-06-09 Numbering of the buttons changed so on the PCB S0 is left upper, S1 is right upper and so on. A more logical assignment of the buttons.
2018-07-09 Hard coded time replaced with define and removed non used define.
    [WifiManualControl.ino]
2018-07-09 Added RC combination for filtering pulse switch.
2018-08-02 Missing labels added for pulse switch bus signals.
2018-08-29 Added (Dutch language) OpenOffice Calc sheet with overview of menu's and actions. Sheet is created by Paul ( http://members.home.nl/pamali/ ).
    [menustructuur.ods]
2018-09-23 Added enlarged component PCB overview of the REV01 version. This version has NO extra components for the pulse switch and has the missing 3V3 supply voltage to the LCD.
2018-11-16 R2 changes to 2K2 for better adc levels of pressed switches.
2018-11-17 Updated for REV02 version. Please use 2k2 for R2 instead of 1K for better detection of buttons connected to the ADC input.
2019-01-09 Pulse switch handling updated.
2019-07-02 Power off command when entering menu removed.
2020-04-27 * The interrupt is changed to CHANGE. For best performence add "debounce" resistors and capacitors. * Replaced bin file.
    [WifiManualControl.ino]
2020-10-19 Updated interrupt declaration of encoder input.
2020-11-03 1.1 Used components Test of resistors updated.
2020-11-08 Bin file version 3.02.00. * Added option to change pulse switch direction using command pulse.
2020-12-26 Added Eagle files.
    [wmc.brd, wmc.sch]
2020-12-29 Version 3.03.03 * Loc selection made faster. During selecting a loc no data is requested from the command station about the loc, only when the push button is released. * Turnout off command corrected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
2022-01-12 Added version 3.03.01. When in cv mode and pressing short no exit from cv anymore, was quite irritating. Exit cv mode is now power button.
